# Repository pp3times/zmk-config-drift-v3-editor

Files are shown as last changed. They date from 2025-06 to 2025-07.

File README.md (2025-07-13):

## Drift Keyboard V3 by Timception - Dual Roller Encoder Firmware   

- This is the wireless [ZMK](https://zmk.dev/) version of the [Original Drift Keyboard](https://github.com/Timception/Drift)  

  - [Default Keymap](#default-keymap) to see where all your keys are, or go straight to the:  
  
    - [Keymap Editor by Nick Coutsos](https://nickcoutsos.github.io/keymap-editor/)  

- The PCB is not open source, but you could [contact me](https://www.instagram.com/majin.keyboards) if you would like a pair
  <br/>  

## Quickstart Guide   
  - [1.	How to change your keys](/docs/change-keys/) - Detailed guide on how to change your keys  

  - [2.	How to install batteries](/docs/batteries/) - Along with other supported batteries  

  - [3.	Connecting through Bluetooth](/docs/bluetooth/) - Bluetooth connections and troubleshooting  

  - [4.	Charging](/docs/charging/) - How to charge the keyboard and use with USB-C  

  - [5.	Switching to low profile](/docs/low-profile/) - Remove some parts to use low profile switches  

  - [6.	3D Printables](https://github.com/Timception/3d-printables) - This will take you to the 3D printable part repository  
<br/><br/>  

# Default Keymap

  - This keyboard is powered by [ZMK](https://zmk.dev/), an open‑source firmware. ZMK lets you place several “layers” of key functions on the same physical keys. When you press a designated layer key—much like holding "Fn" on a laptop—the keyboard shifts to a different layer, giving you extra controls (for example, volume, brightness, or any custom shortcuts) without adding more keys.  

  - Split keyboards come with their own set of terms, and one important one to know is the “thumb cluster.” This refers to the group of keys at the bottom in the form of an arc where a traditional keyboard would have the spacebar.  
    
  - Unlike standard keyboards, split keyboards make better use of this space by letting you place and customize useful keys there. This reduces the need to reach for commonly used keys.  

  - For example, on this keyboard, I’ve placed Shift on the left-most thumb cluster key and Backspace on the right-most. The spacebar is in the center of each thumb cluster—so whether you hit the spacebar with your left or right thumb, it’s easy to reach.  

  - You can [change the keys on your keymap](/docs/change-keys/) if you prefer different placing of any key.  

> [!Note]  
> The "&trans" keys seen on the thumb clusters on layers 1 and above act as transparent keys, copying the key set on the layer beneath it.  
> If you are confused about what some of these keys represent, you may find [more information here](https://zmk.dev/docs/keymaps/list-of-keycodes)  
> Information on layers can also [be found here](https://zmk.dev/docs/keymaps/behaviors/layers)  

## Base/Default Layer (layer 0)  
- This is the default layer or layer 0 on this keyboard and the keys are as follows:  
  
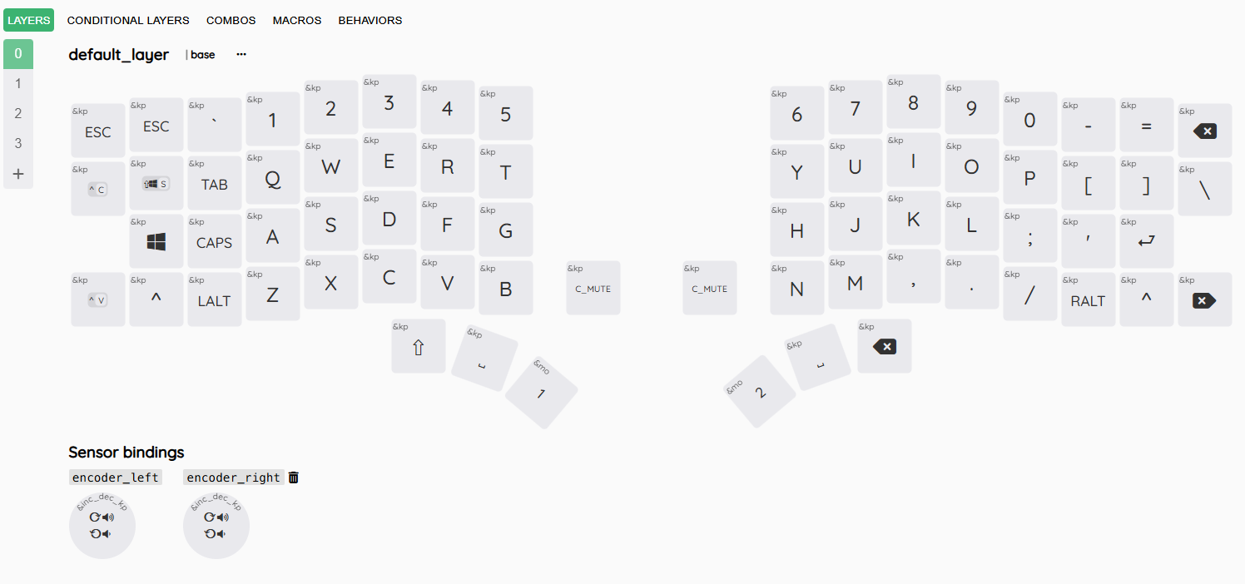
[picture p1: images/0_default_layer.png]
  <br/><br/>  

## Lower Layer (layer 1)  
- This is the lower layer or layer 1. This is where the F-Keys and Arrow-Keys are:  
  
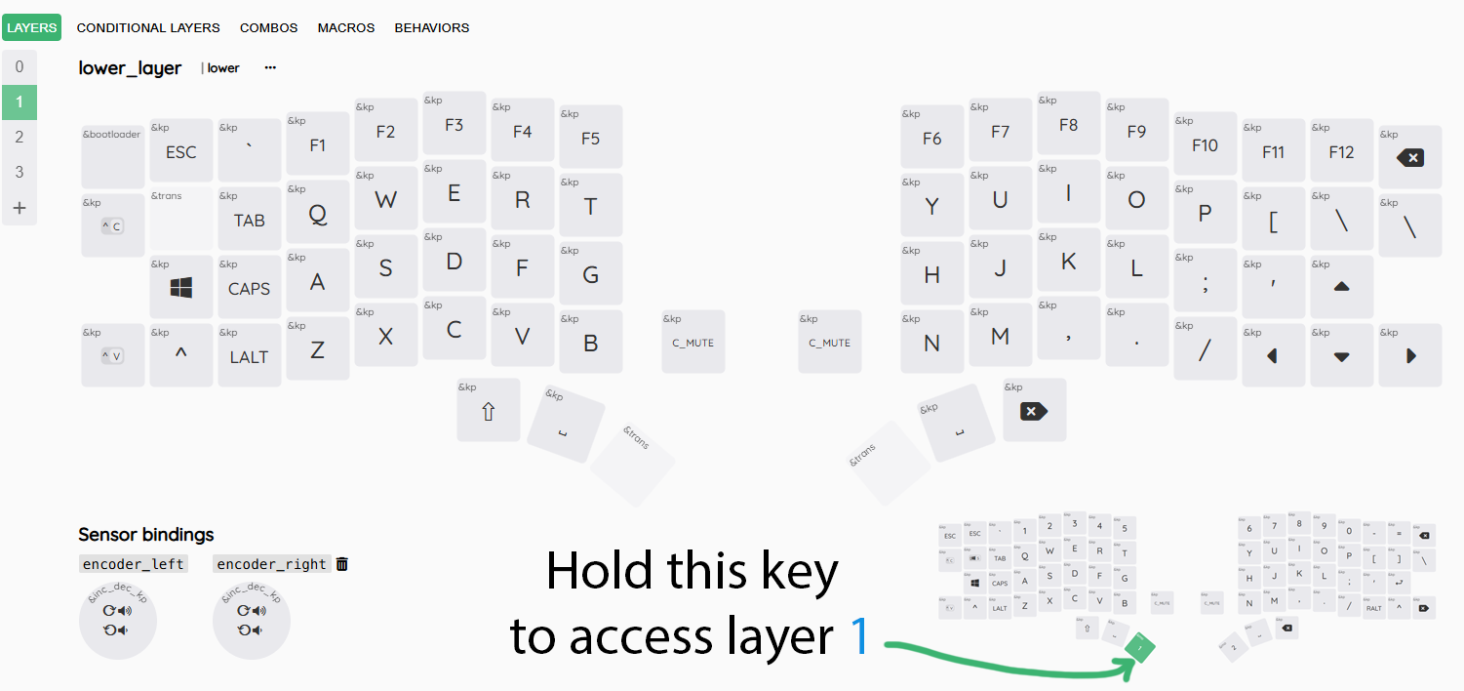
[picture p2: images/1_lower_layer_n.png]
    
  The "&mo 1" key is held to access this layer as seen in the bottom right of this image.  <br/><br/>  

## Raise Layer (layer 2)  
- This is the lower layer or layer 2. This is where the Bluetooth Functions and Mouse Keys are:  
  
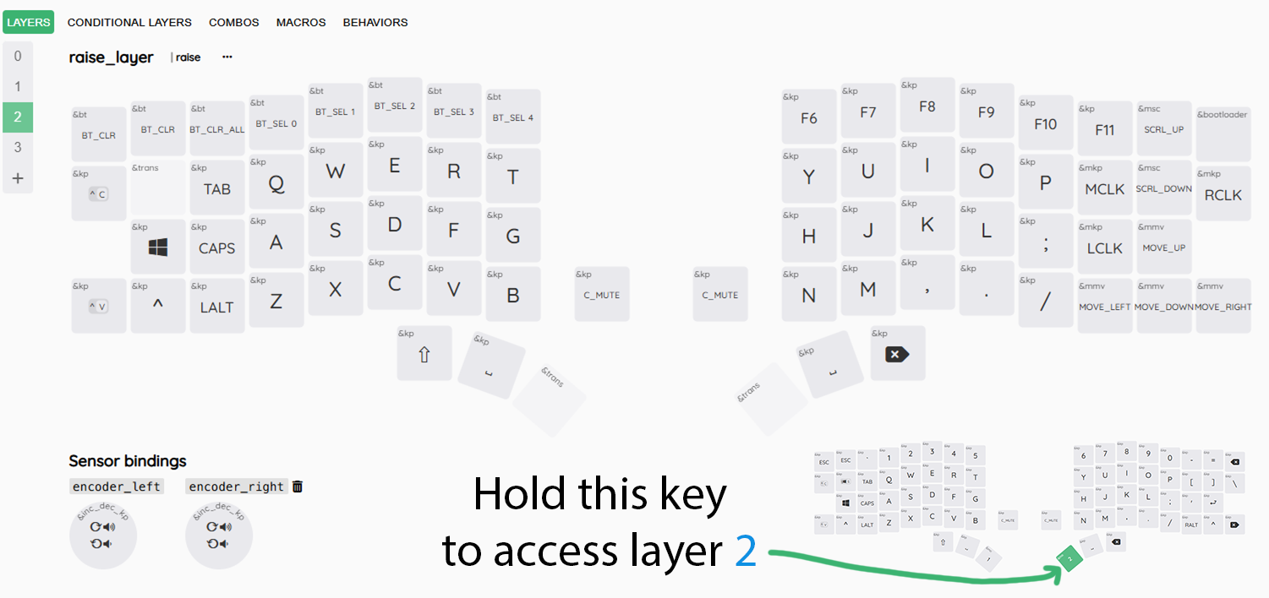
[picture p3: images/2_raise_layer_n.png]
    
  The "&mo 2" key is held to access this layer as seen in the bottom right of this image.  <br/><br/>  

## Adjust Layer (layer 3)  
- This is the adjust layer or layer 3. This is pretty much a clone of Layer 2 as my usage doesn't go beyond 3 layers:  
  
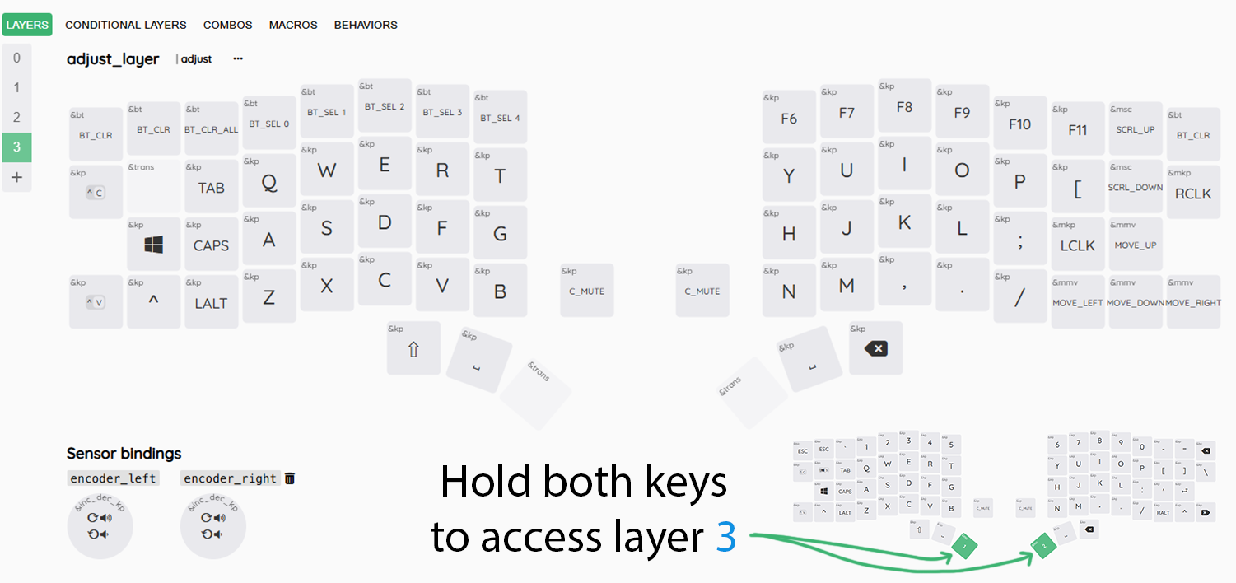
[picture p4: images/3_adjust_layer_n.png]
    
   Both "&mo 1" and "&mo 2" keys are held to work together to activate the conditional layer function, taking us to layer 3.  <br/><br/>  

This version of the Drift Keyboard supports:  

 - 5-Pin MX switches (3-Pin switches will also work)  
 - Kailh Choc V1 switches  
 - Kailh Choc V2 switches  
<br/>  

How to [change your build](/docs/low-profile/) to use choc switches.  
<br/>  

  
<br/>  

>[!Warning]
>Important Note on LiPo Batteries  
>  
>LiPo (Lithium Polymer) batteries are considered a fire hazard due to their sensitivity
>to overcharging, punctures, or improper handling, which can lead to overheating or combustion.
>Because of strict shipping regulations, LiPo batteries cannot be included with this keyboard
>and must be purchased separately by the builder.  
>  
>Disclaimer: I am not responsible for any damage, injury, or loss resulting from the use,
>charging, or installation of LiPo batteries. Use at your own risk and follow all safety guidelines
>provided by the battery manufacturer.  
>  
>More on how to install batteries [here](/docs/batteries/)  
<br/><br/>  

You can see more actual builds [HERE](https://www.instagram.com/majin.keyboards)  

This project was made possible thanks to the incredible support of [Friction](https://github.com/friction07)  
Your generosity truly made all the difference—thank you!

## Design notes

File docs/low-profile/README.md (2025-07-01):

## Drift Keyboard Choc Conversion
This is how to convert to a low-profile choc version:  

### Basically you only have to remove one layer of the outer acrylic frame  
<br/>

 - Disassemble your drift keyboard then remove all the brass standoffs  
 
 - Replace all the brass standoffs with 4mm brass standoffs  
 
 - The top screws under the keys should be changed to 4mm M2 screws if they are not already that length.  
 
 - You will need to use the [Choc Plate](https://github.com/Timception/3d-printables/tree/main/v3/plates/low-profile) which is slightly different from the MX switch plate.  
 <br/><br/>  
 
### This is what your Drift Keyboard should look like after the conversion:  
<br/><br/>  

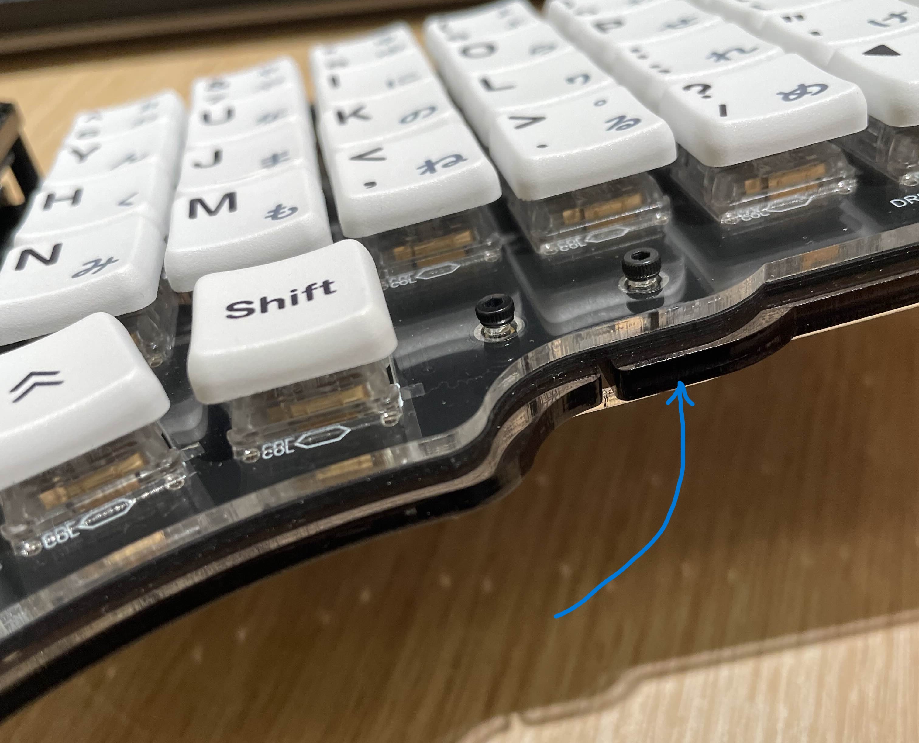
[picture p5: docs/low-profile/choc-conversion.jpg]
  

Only one layer of outer acrylic beneath the pcb, and the plate is now sandwiched flush with the pcb.

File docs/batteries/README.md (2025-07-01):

# Battery Installation  

## Contents:  

 - [3D Printables for PS3 Controller Battery Pack](https://github.com/Timception/3d-printables/tree/main/v3/battery-pack) - Takes you to the 3D printables page for these parts
 
 - [Batteries](#batteries-tested-to-work-with-the-keyboard) - Some batteries you can use for this keyboard  
   
 - [Screwing on the PS3 controller battery pack](#screwing-on-the-ps3-controller-battery-pack) - Start of the assembly guide  
 
 - [Plugging in the Battery Connector](#plugging-in-the-battery-connector) - Hooking up the battery  
 
 - [Plugging in the 4-Pin OLED](#plugging-in-the-4-pin-oled) - Standard (power hungry) OLED  

## Alternate Battery:  
 
 - [Using the 110mAh LiPo Battery](#using-the-110mAh-lipo-battery-instead) - the smaller battery option (removing the OLED dramatically improves battery life)  

## Alternate Display:  
 
 - [Replacing the 4-Pin OLED with a NiceView](#replacing-the-4-pin-oled-with-a-niceview) - Best screen to use if you install the 110mAh battery  
<br/><br/>

>[!Warning]
>Important Note on LiPo Batteries  
>  
>LiPo (Lithium Polymer) batteries are considered a fire hazard due to their sensitivity
>to overcharging, punctures, or improper handling, which can lead to overheating or combustion.
>Because of strict shipping regulations, LiPo batteries cannot be included with this keyboard
>and must be purchased separately by the builder.  
>  
>Disclaimer: I am not responsible for any damage, injury, or loss resulting from the use,
>charging, or installation of LiPo batteries. Use at your own risk and follow all safety guidelines
>provided by the battery manufacturer.  
<br/><br/>  

## Batteries tested to work with the keyboard

- 1800mAh PS3 Controller Battery (LIP1359)
   
  - [Amazon Item Link](https://a.co/d/4CgXvFp)  
  - [Aliexpress Item Link](https://www.aliexpress.com/item/1005005213892382.html)  
  <br/>  

- 120mAh LiPo Battery (401230) + JST PH2.0mm - This battery is small enough to fit under the MCU
  
  - [Aliexpress Item Link](https://www.aliexpress.com/item/1005003383250806.html)  
  <br/>  
  
- 110mAh LiPo Battery (401030) + JST PH2.0mm - This battery is small enough to fit under the MCU
  
  - [Ebay Item Link](https://www.ebay.com/itm/124961007813)  
  - [Aliexpress Item Link](https://www.aliexpress.com/item/1005006161362814.html)  
  <br/>  

## Screwing on the PS3 controller battery pack  

1. Make sure this screw is already screwed into the nylon standoff on the other side.  

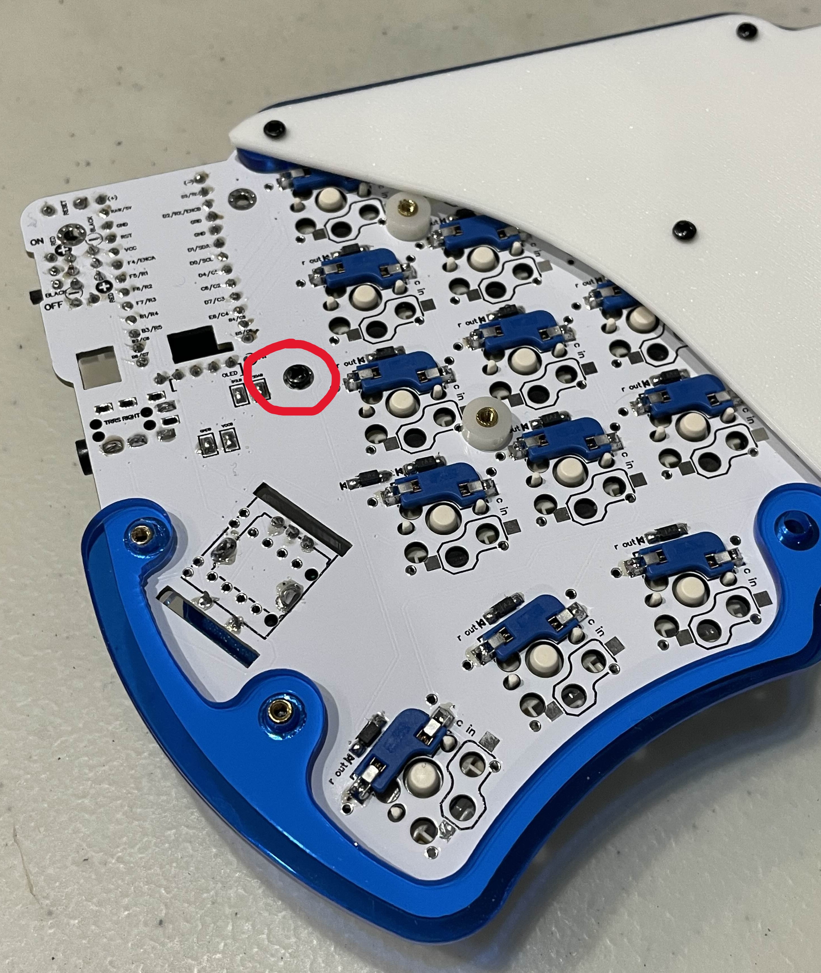
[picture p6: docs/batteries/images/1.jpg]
<br/><br/>

2. Place Bottom Plate Section and Screw in this 12mm screw first.  

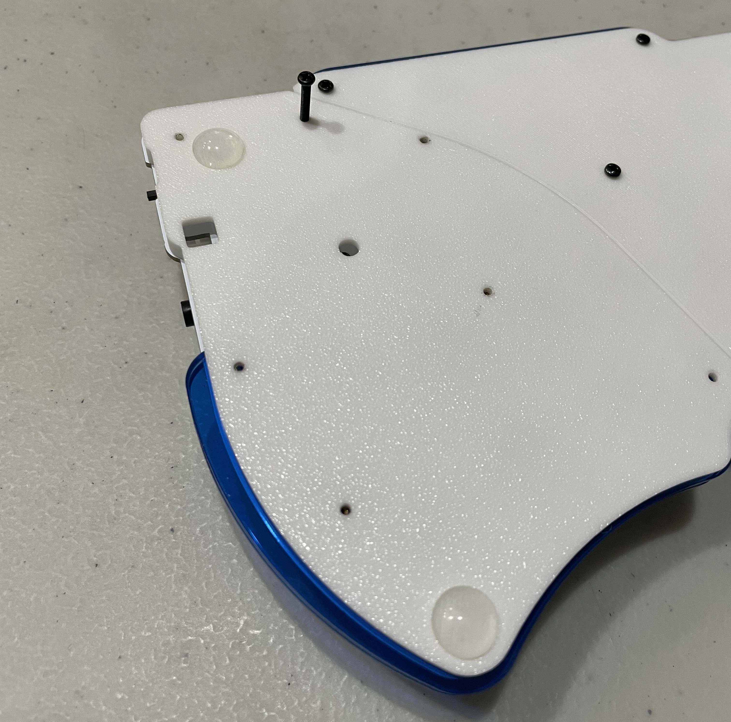
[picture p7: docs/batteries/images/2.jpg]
<br/><br/>

3. Screw in the nylon standoff as shown below.  

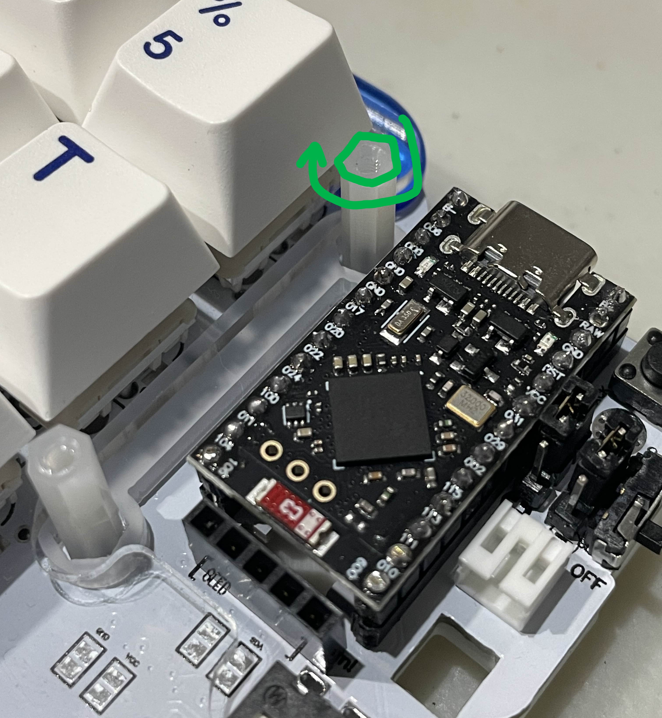
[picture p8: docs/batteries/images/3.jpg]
<br/><br/>

4. Here is how the battery will fit in the 3D-Printed battery pack.  

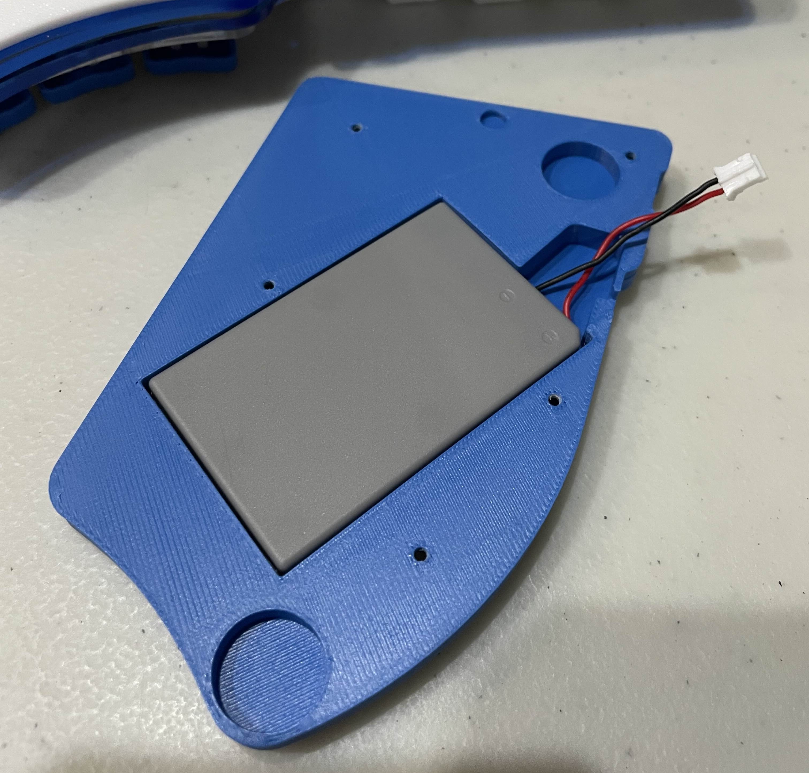
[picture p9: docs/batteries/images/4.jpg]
<br/><br/>

5. First, put the JST PH2.0 battery connector through to the other side as shown below.  

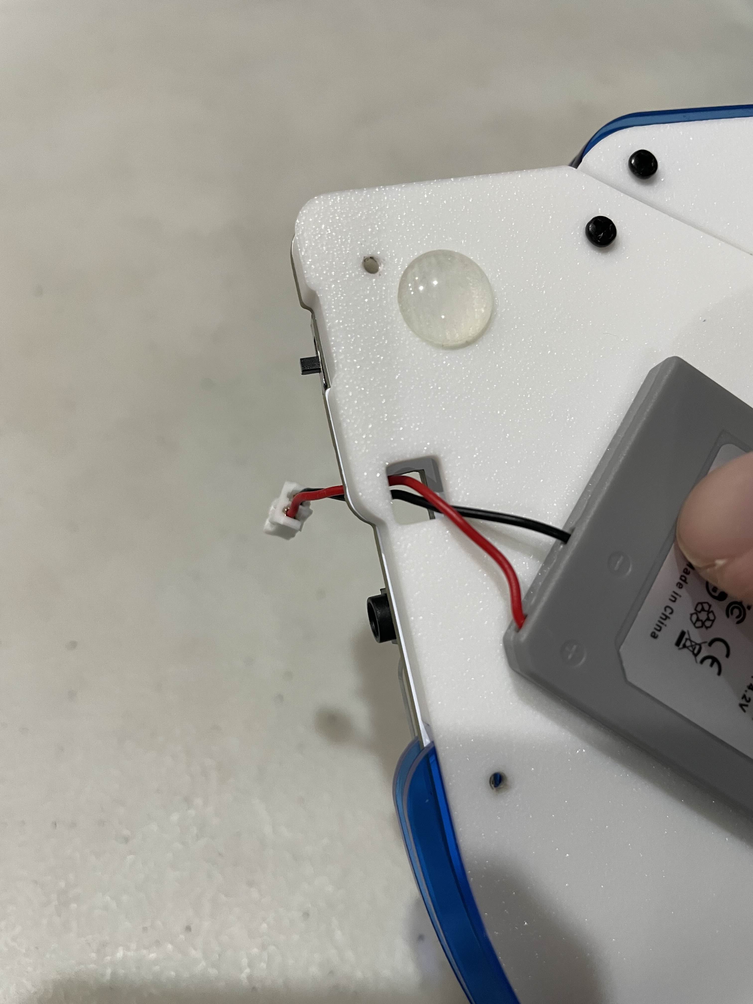
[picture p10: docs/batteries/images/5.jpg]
<br/><br/>

6. Next, carefully place the battery cover over the battery.  

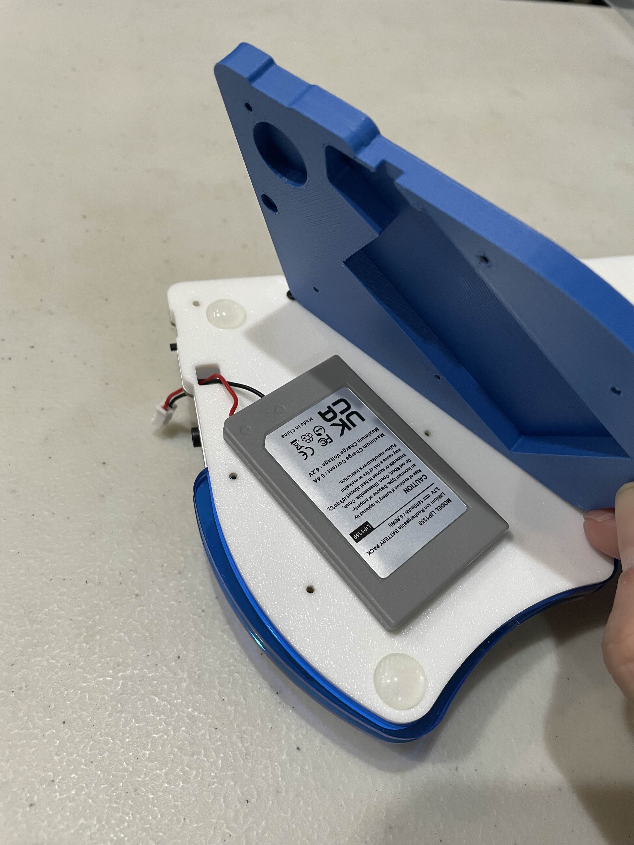
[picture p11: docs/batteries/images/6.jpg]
<br/><br/>

7. Align/Adjust the cover so the screw holes match the plate underneath.  

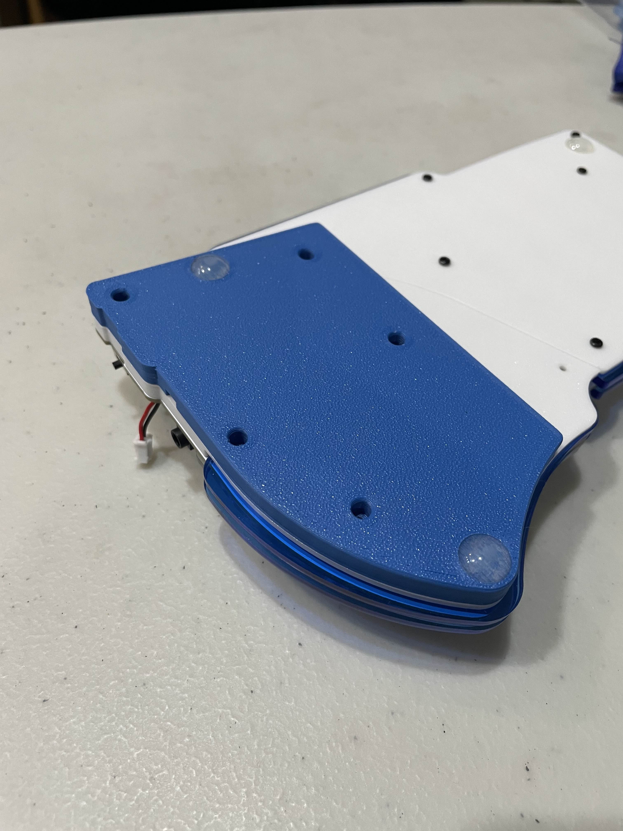
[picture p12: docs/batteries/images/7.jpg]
<br/><br/>

8. Now screw in this 5mm M2 screw as shown in the image.  

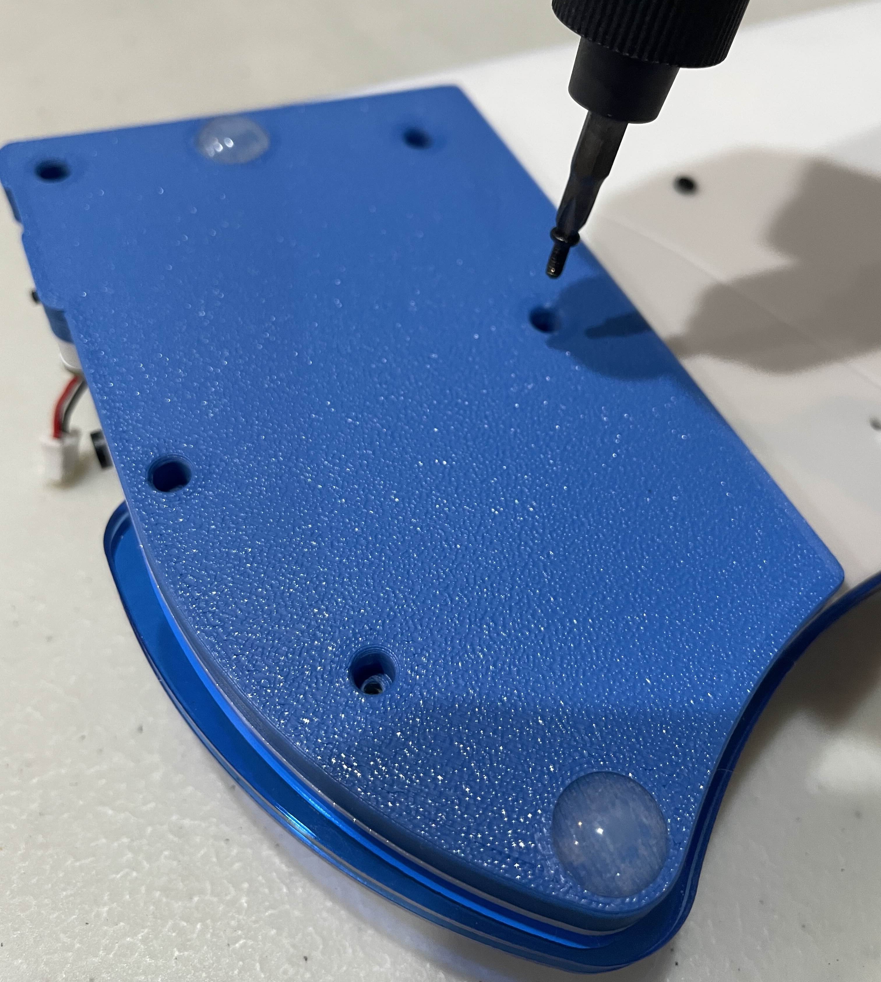
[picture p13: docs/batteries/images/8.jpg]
<br/><br/>

9. Next, screw in this screw.  

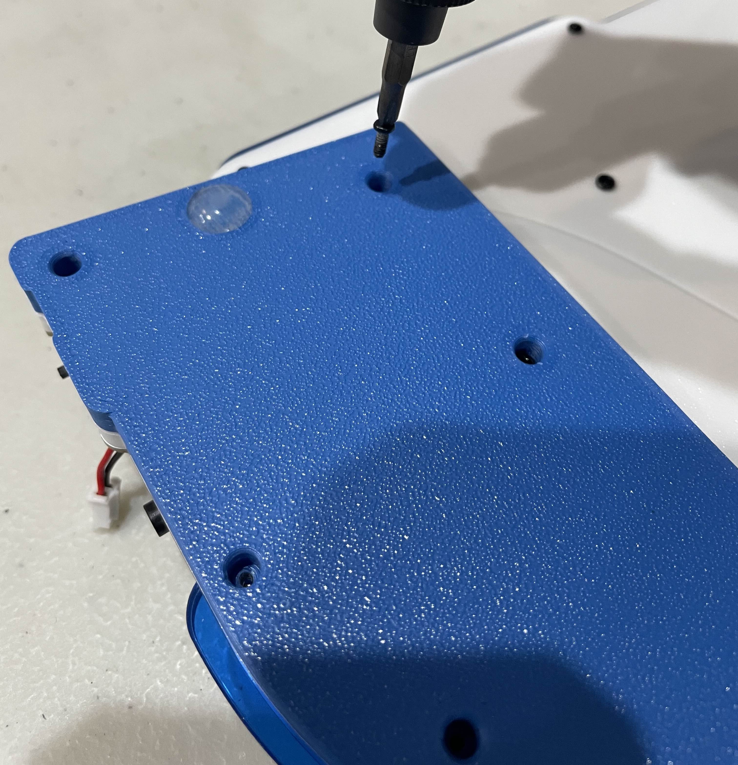
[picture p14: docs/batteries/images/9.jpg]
<br/><br/>

10. Then this 12mm screw as shown.  

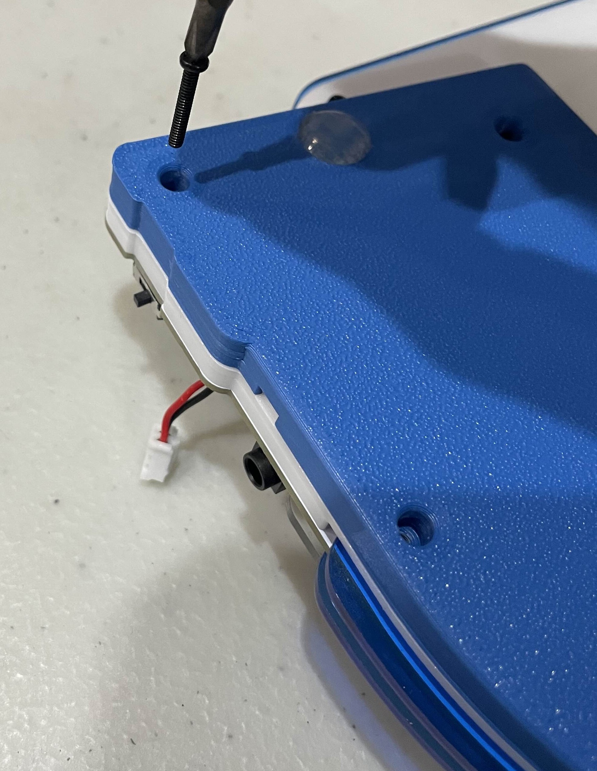
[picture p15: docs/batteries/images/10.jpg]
<br/><br/>

11. Screw in the nylon standoff seen just under the RESET switch.  

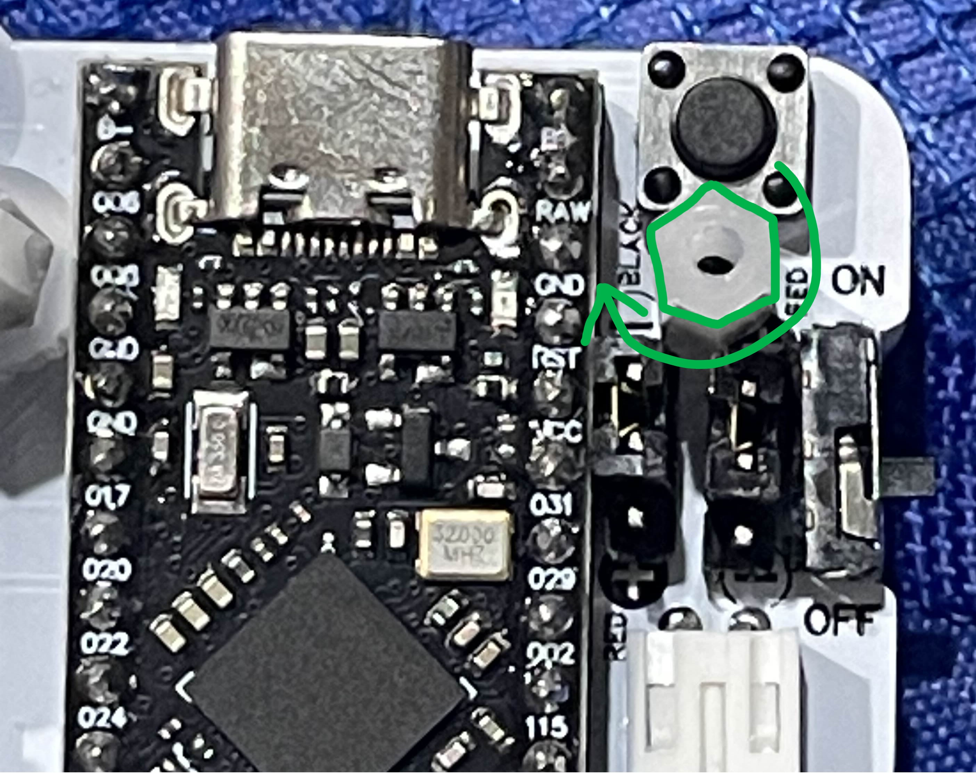
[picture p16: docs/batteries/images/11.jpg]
<br/><br/>

12. Next screw back in the hex nut with the brass standoff and leave the allen key wrench in.  

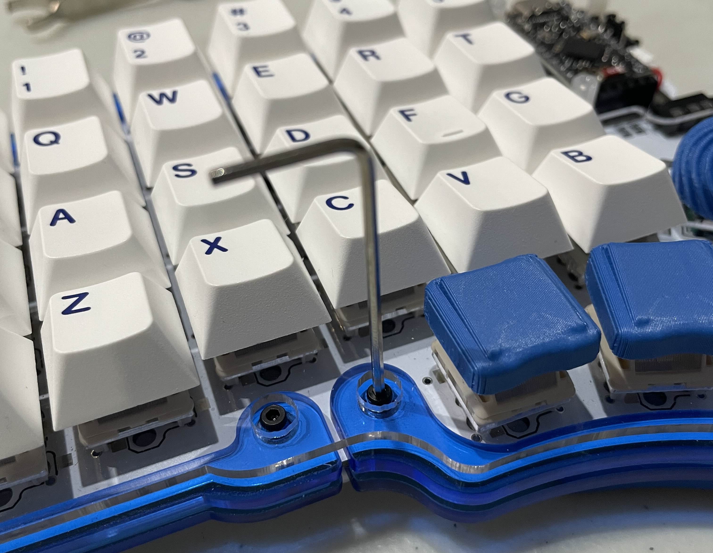
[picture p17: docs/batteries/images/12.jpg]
<br/><br/>

13. Hold the allen key wrench in position to prevent it from spinning as you screw in from the other side as shown below.  

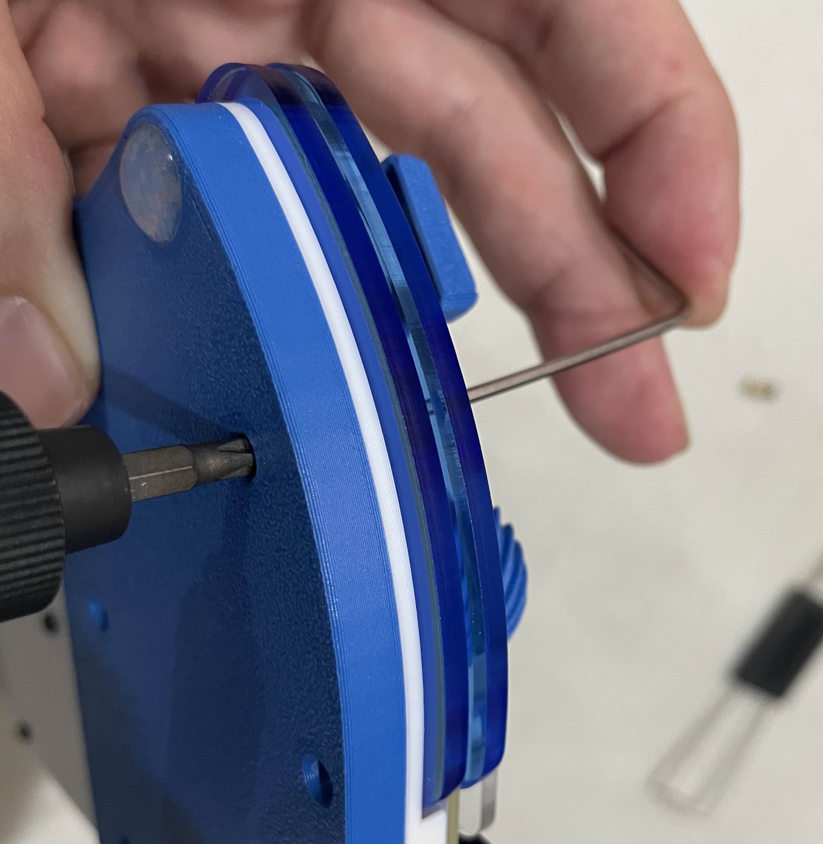
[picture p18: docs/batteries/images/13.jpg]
<br/><br/>

## Plugging in the Battery Connector  

14. Now insert the battery connector by hand, with the help of tweezers or the switch puller as shown.  

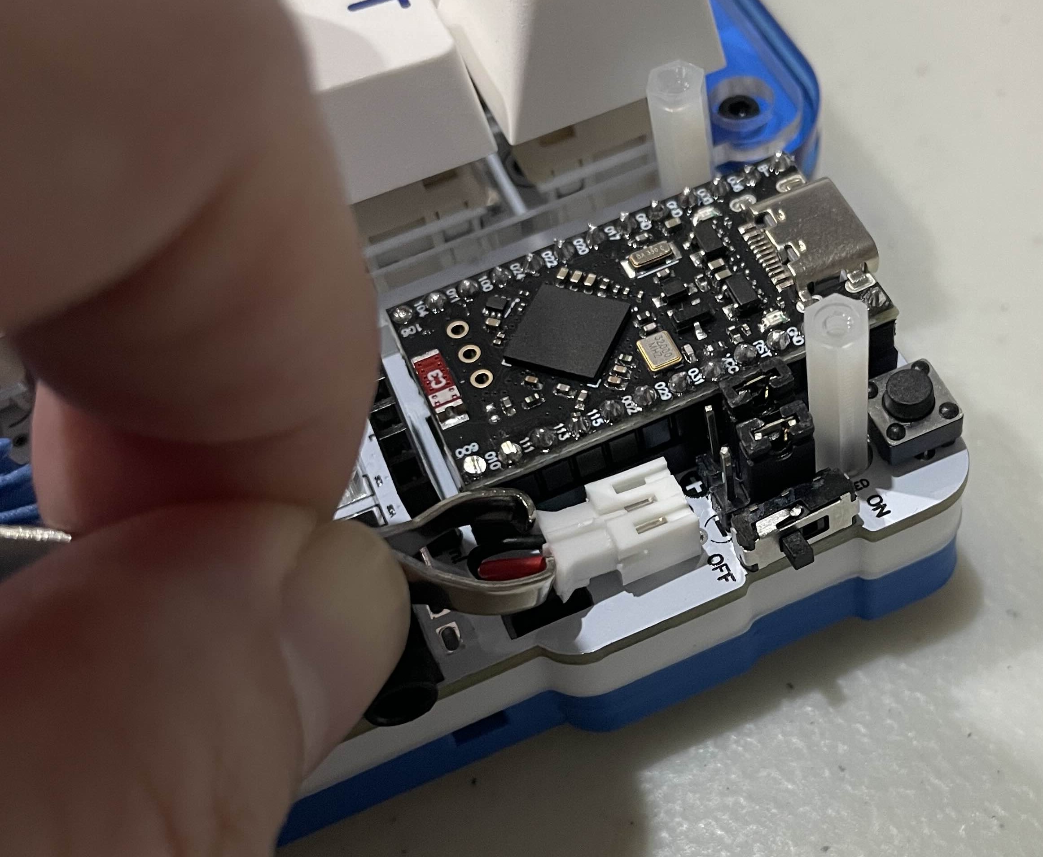
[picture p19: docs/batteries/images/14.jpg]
<br/><br/>

15. Make sure the jumpers are over the correct pins as shown in the image (they should be correct straight out of the box).  

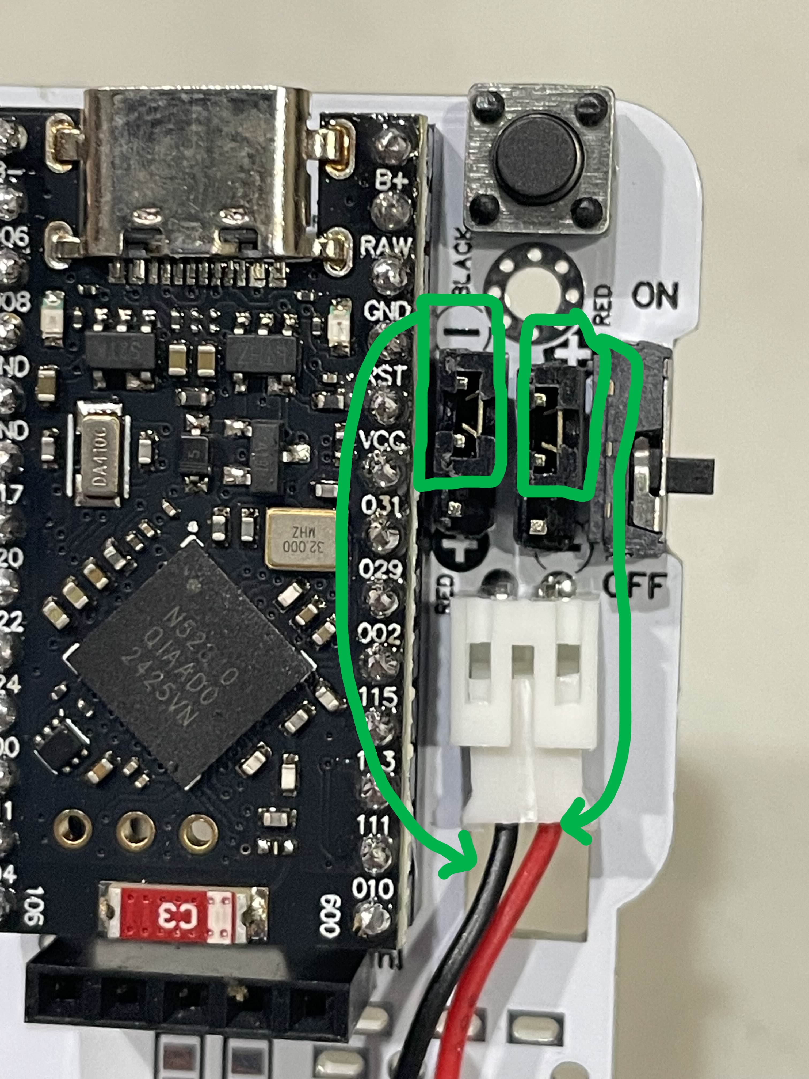
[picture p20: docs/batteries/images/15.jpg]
<br/><br/>

16. Do the same for the right half and see if the cable colors and jumpers are the same as in the image below.  

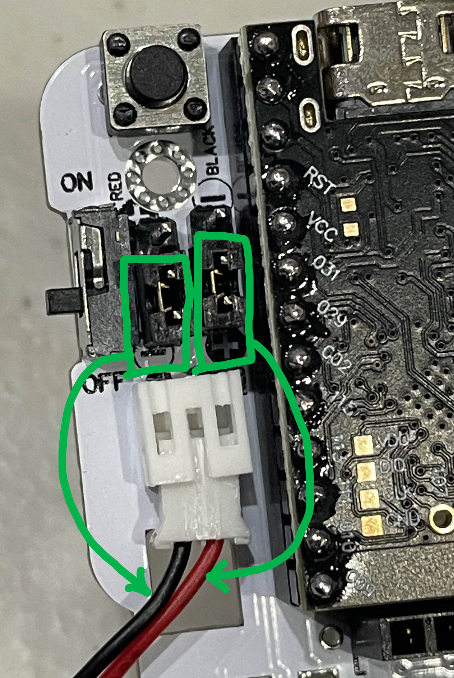
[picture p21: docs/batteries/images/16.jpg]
<br/><br/>

17. Place the 3D-Printed cover over the MCU so that it is flush with the PCB.  

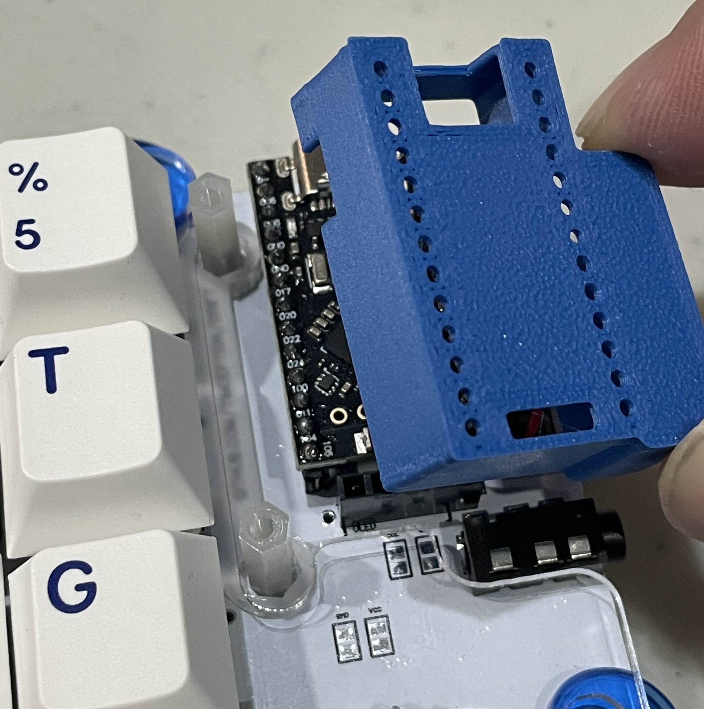
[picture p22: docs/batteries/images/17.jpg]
<br/><br/>

## Plugging in the 4-Pin OLED  

18. Insert the 4-Pin OLED into the left female pin headers as shown in the image for both sides.  

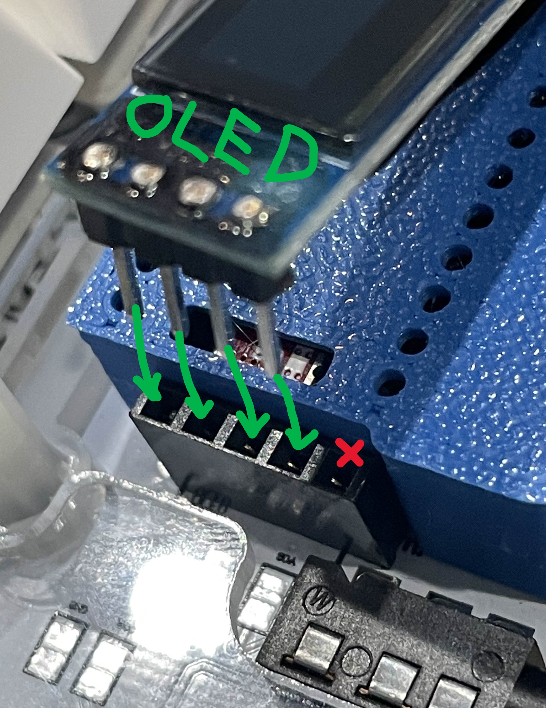
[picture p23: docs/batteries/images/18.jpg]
<br/><br/>

# Using the 110mAh LiPo Battery instead  

19. Remove the MCU carefully with a switch puller.  

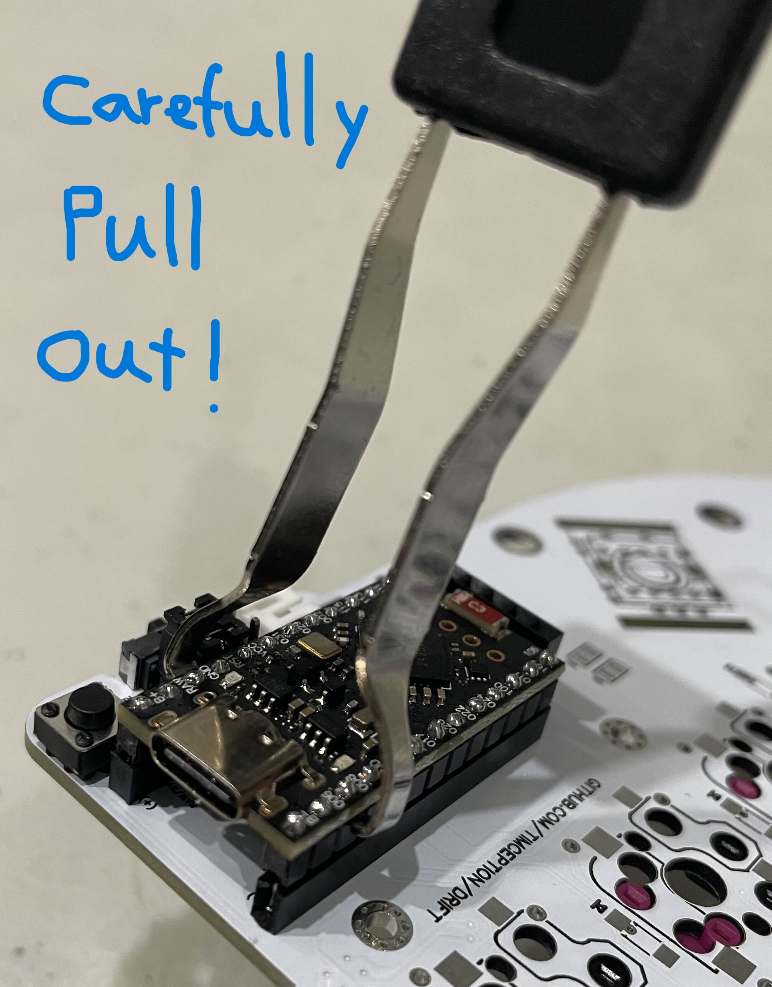
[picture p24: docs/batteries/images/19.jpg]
<br/><br/>

20. Insert the connector through the hole as shown.  

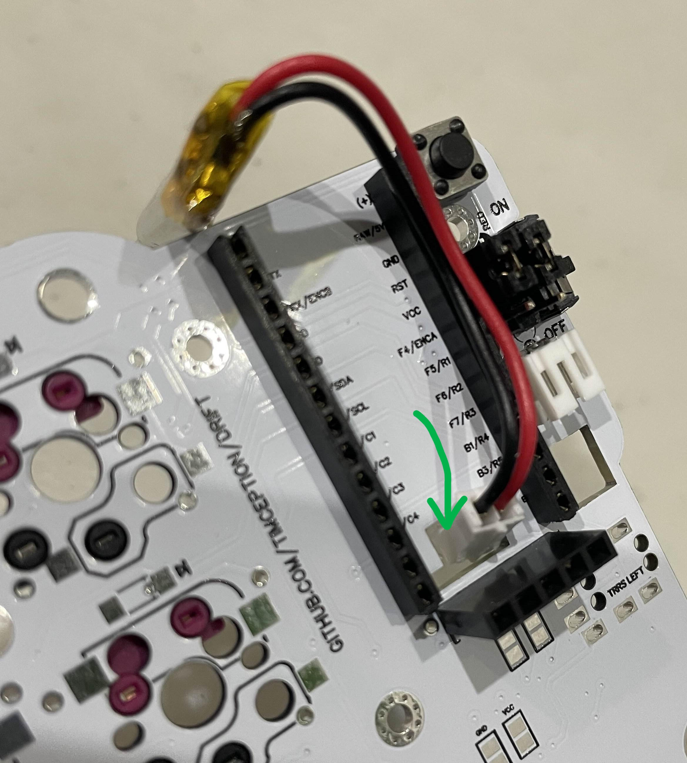
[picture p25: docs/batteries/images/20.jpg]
<br/><br/>

21. Push the connector back out the other hole as shown.  

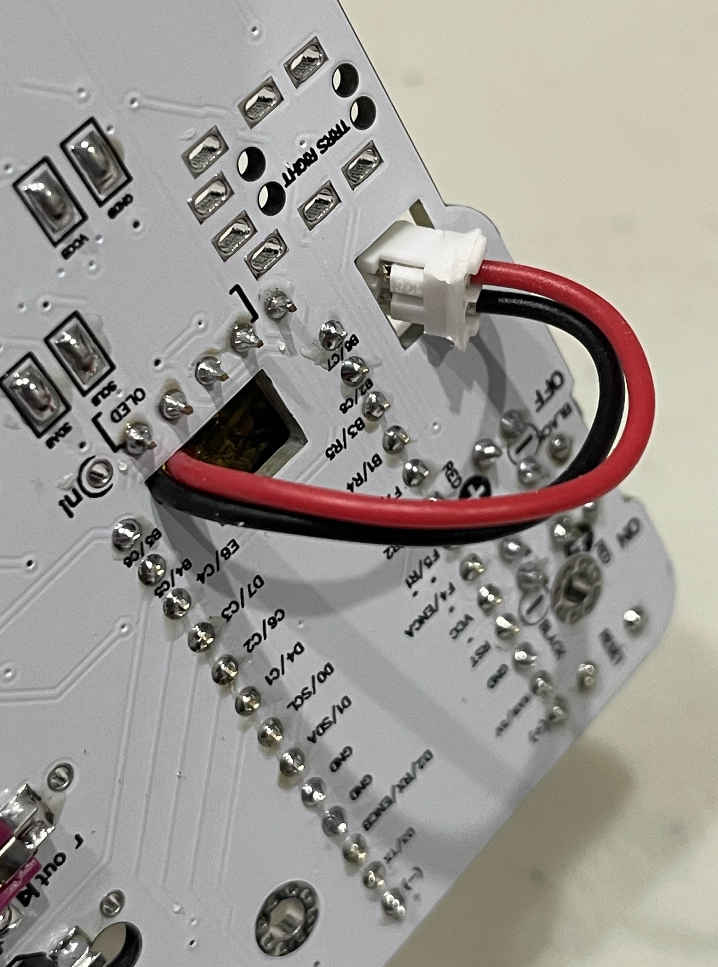
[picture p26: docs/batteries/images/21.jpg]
<br/><br/>

22. Try to avoid the pins puncturing into the wire to prevent unwanted short circuits (electrical tape can be used to cover the pins).  

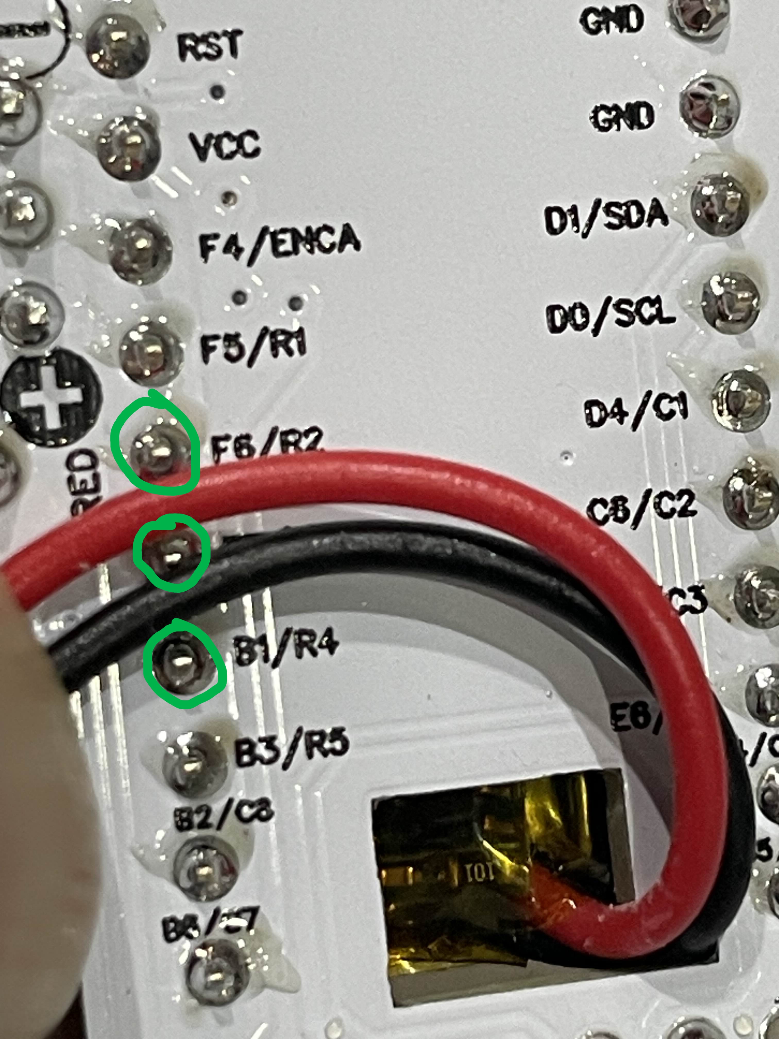
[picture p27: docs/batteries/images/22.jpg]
<br/><br/>

23. Check that you have moved the pins to the correct positions as shown before plugging in the battery connector.  

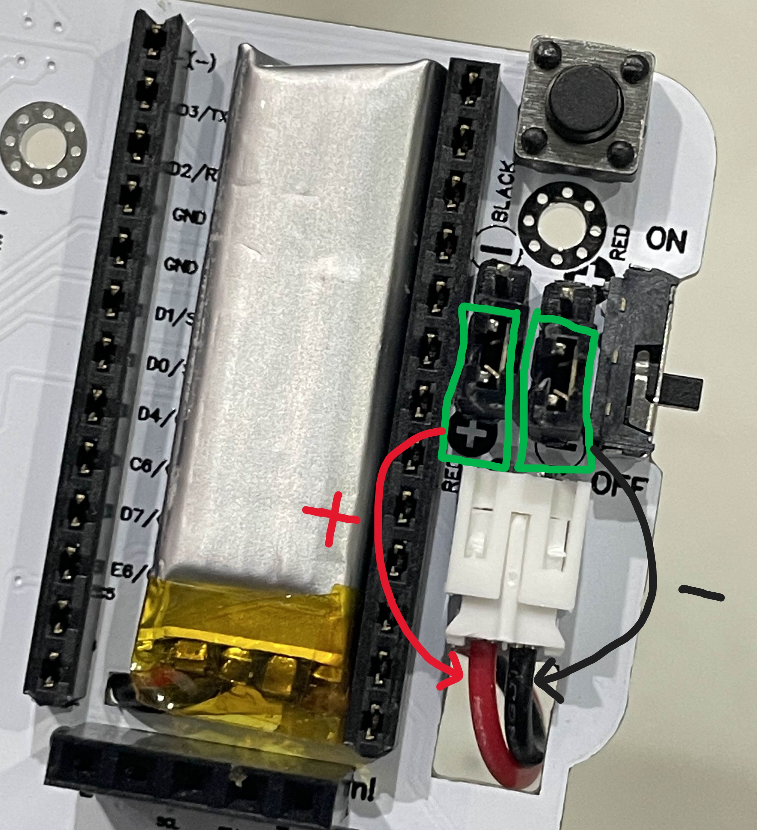
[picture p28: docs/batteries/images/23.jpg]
<br/><br/>

24. Carefully push the MCU back into its place with the pins aligned correctly.  

<br/><br/>

25. Repeat the process for the right half with the jumpers placed as shown.  

<br/><br/>

# Replacing the 4-Pin OLED with a NiceView

26. You can replace the normal OLED with a super efficient screen famously known as the [Nice!View](https://nicekeyboards.com/nice-view/)

> [!Warning]  
> You will need to flash a [special version of firmware](https://github.com/Timception/zmk-config-drift-v3-nv-editor) on to both sides before inserting the Nice!View
> 
<br/><br/>

> [!Note]
> If you forgot how to fork and compile your own firmware, [please refer to this guide](https://github.com/Timception/zmk-config-drift-v3-editor/tree/main/docs/change-keys)
<br/><br/>

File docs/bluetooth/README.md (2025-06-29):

# Testing or Fixing your Bluetooth Connection

- ## Connect to Mutliple Devices  

  - Once you turn on your split keyboard you can clear the current bluetooth profile just to make sure it is available by pressing the BT_CLR or BT_CLR_ALL key on layer 2.  
  
  - You can enable/refresh bluetooth on your host device to search for this keyboard and connect to it. If it says unable to connect - you can try clicking on the device in the list repeatedly (I spam click in Windows until it connects).  
  
  - This keyboard has the ability to connect to 5 devices across 5 Profiles (BT_SEL 0 to BT_SEL 4).  
  
  - By holding down mo2 as shown below, you have access to the bluetooth functions on the top left half:
  - <br/>  
    
    - BT_CLR: Clear the connection between the keyboard and host for the selected profile.  
	
    - BT_CLR_ALL: Clear the connection between the keyboard and host for all profiles.  
	
    - BT_SEL 0 to BT_SEL 4: Pressing BT_SEL 0 will activate the first bluetooth profile, BT_SEL 1 will activate the second, and so on..  
	
    - If thirsty for more information [CLICK HERE](https://zmk.dev/docs/keymaps/behaviors/bluetooth)  

- ## Clearing a Bluetooth Profile (also removing keyboard from host device)  

  - After pressing BT_CLR or BT_CLR_ALL, you will also have to remove the device from your host. Usually this consists of going into the host device's bluetooth settings with bluetooth turned on and manually removing the drift keyboard from the list of devices (if any).  

<br/><br/>

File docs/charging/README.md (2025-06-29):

# Charging and Wired Connection

- The keyboard halves must be charged individually through their USB-C port, with the power switches turned on.

- Standard USB-C phone chargers (5V, 1A–2.4A) will also work.

- A blue light will appear near the USB-C port while charging. The light turns off when charging is complete.
<br/><br/>

> [!Note]  
> You can usually see the battery percentage of connected Bluetooth devices on your computer or phone.  
> Because of this, an OLED screen is not really needed, unless you use [these](https://typeractive.xyz/products/nice-view). Removing the OLED can greatly improve battery life.  
> If you want to use this keyboard through a USB-C wired connection without charging, both sides must be connected to your computer individually.  

> [!Warning]  
> Connecting only the right half will not work. However, connecting only the left half will work.  
> This is because the right half must first communicate with the left half before sending signals to the computer.  
> As a result, the battery on the left half drains faster than the right.  
<br/>

- [ZMK Power Profiler](https://zmk.dev/power-profiler) - Please check this out to estimate your keyboard's power usage and battery life with different components.  
<br/>


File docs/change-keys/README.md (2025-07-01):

# How to Change your Keymap on GitHub (step by step)  

## Summary of tasks:  

  - Login to GitHub, [fork keyboard repository](#1-fork-this-repository)  
  - [Enable workflows/actions](#4-enable-workflows) (to pump out your own firmware)  
  - [Enable keymap editor](#12-click-the-keymap-editor-link) (to edit your keymap)  
  - [Save keymap changes](#24-click-save-at-the-top-to-save-your-new-keymap), download new firmware  
  - [Flash keyboard firmware](#28-plug-left-half-of-the-drift-keyboard-into-your-computer-then-double-click-the-reset-button) one side at a time, enjoy  
<br/><br/>  

## Follow the illustrated guide below if this is your first time  

### 1. Fork [This Repository](https://github.com/Timception/zmk-config-drift-v3-editor)  

<br/><br/><br/>  

### 2. Set Repository Name and Create Fork  

<br/><br/><br/>  

### 3. Go to the Actions Tab  

<br/><br/><br/>  

### 4. Enable Workflows  

<br/><br/><br/>  

### 5. Click Build your ZMK Firmware  

<br/><br/><br/>  

### 6. Run Workflow  

<br/><br/><br/>  

### 7. Wait for GitHub to Compile Firmware Files  

<br/><br/><br/>  

### 8. Click the Firmware Link after Build Complete  

<br/><br/><br/>  

### 9. Download Firmware  

<br/><br/><br/>  

### 10. Unzip to Find 3 Files: Firmware Files for the Left and Right Keyboard Halves and a Reset File  
This confirms that you can now make your own firmware. Next, let's try and change some keys.  

<br/><br/><br/>  

### 11. Go Back to the Repository Page  

<br/><br/><br/>  

### 12. Click the [Keymap Editor Link](https://nickcoutsos.github.io/keymap-editor/)  

<br/><br/><br/>  

### 13. Authenticate with GitHub  

<br/><br/><br/>  

### 14. Authorize Keymap Editor  

<br/><br/><br/>  

### 15. Add Repository  

<br/><br/><br/>  

### 16. Add Select Repository - Drift V3  

<br/><br/><br/>  

### 17. After Installation - Keymap will Appear  

<br/><br/><br/>  

### 18. Click the Layer Numbers to View the Keys on Each of those layers  

<br/><br/><br/>  

### 19. You can Access the Bluetooth Functions by Pressing and Holding "mo2"  

<br/><br/><br/>  

### 20. Bluetooth Functions [(more on this here)](https://github.com/Timception/zmk-config-drift-v3-editor/tree/main/docs/bluetooth)  

<br/><br/><br/>  

### 21. Click the "Alt" Key to bring up the Behaviour Settings for that Key  

<br/><br/><br/>  

### 22. Click the Current Key in the Key Code Field  

<br/><br/><br/>  

### 23. Find the Shift Keycode by using the Search Bar then Click "Okay"  

<br/><br/><br/>  

### 24. Click "Save" at the top to Save your New Keymap  

<br/><br/><br/>  

### 25. Note the Changes you Made (optional) and Click "Commit"  

<br/><br/><br/>  

### 26. Click Firmware File Link to go to the Firmware Building Page  

<br/><br/><br/>  

### 27. Download New Firmware after Everything is Green and Complete  

<br/><br/><br/>  

### 28. Plug Left Half of the Drift Keyboard into your Computer then Double-Click the RESET Button  

<br/><br/><br/>  

### 29. A New Drive Should Appear (for you to upload your firmware file)  

<br/><br/><br/>  

### 30. Drop the Firmware for the Left Side into that Drive and Wait for Transfer to Complete  

<br/><br/><br/>  

### 31. Repeat Steps for the Right Half and Drop the Appropriate Firmware File into its Drive  

<br/><br/>

### 32. Test Keys Using This [Online Key Tester](https://www.keyboardtester.com/tester.html) or Download [Switch Hitter](https://www.majorgeeks.com/files/details/switch_hitter.html)  

<br/><br/>

For more information on Behaviours and Key Codes please visit: [ZMK Behaviours](https://zmk.dev/docs/keymaps/behaviors)  

You can see more actual builds [-=HERE=-](https://www.instagram.com/majin.keyboards)

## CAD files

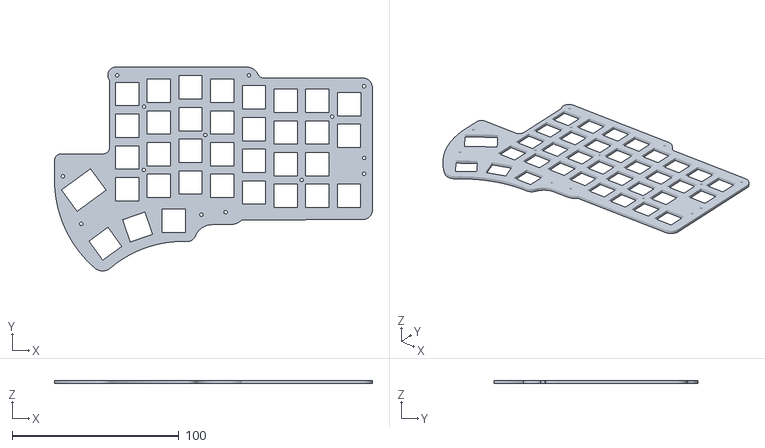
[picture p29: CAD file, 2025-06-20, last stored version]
Drift-V2-and-V3-Choc-Plates/Drift-V2-and-V3-Full-Size-Choc-Plate-right.stl
190.6 x 122.2 x 2.00

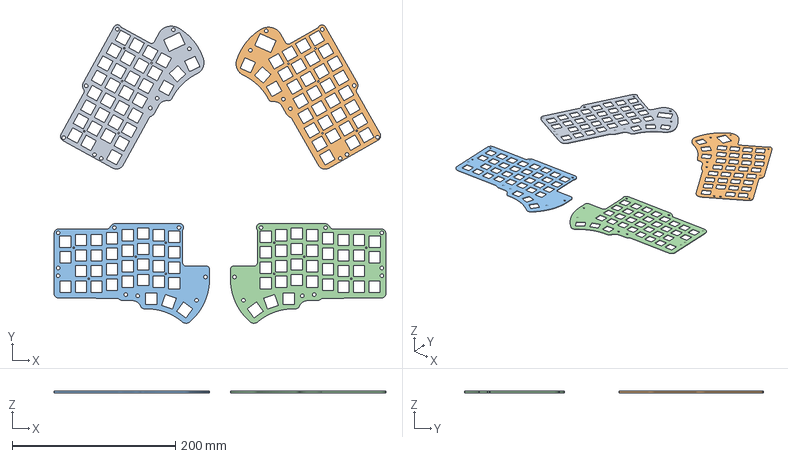
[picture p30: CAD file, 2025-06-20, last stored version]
Drift-V2-and-V3-Cherry-Plates/Drift-V2-and-V3-Cherry-Plates.3mf
406.6 x 365.7 x 2.00 mm
Drift V2 Cherry Plate A1 Mini.stl x 2
Drift-V2-and-V3-Full-Size-Cherry-MX-Plate-left.stl
Drift-V2-and-V3-Full-Size-Cherry-MX-Plate-right.stl

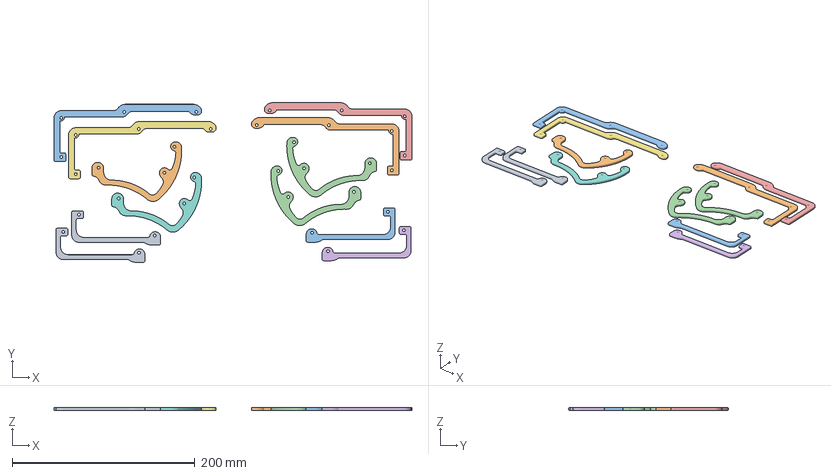
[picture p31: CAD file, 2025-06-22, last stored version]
Outer-Acrylic/Outer-Acrylic-Fillet.3mf
392.3 x 175.1 x 3.00 mm
Bottom Left Acrylic (1) x 4
Bottom Right Acrylic (1) x 4
Top Acrylic (1) x 4

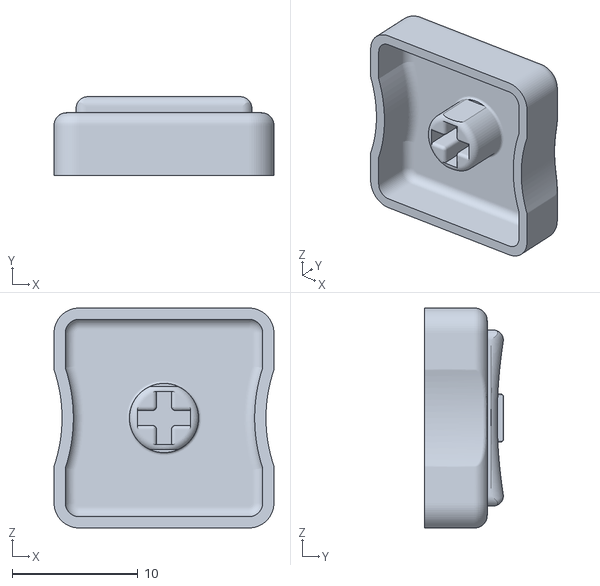
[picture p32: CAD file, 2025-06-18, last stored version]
printables/Cherry-MX/Otaru-Keycaps-by-Timception-Ribbed-Key.stl
17.5 x 6.30 x 17.5

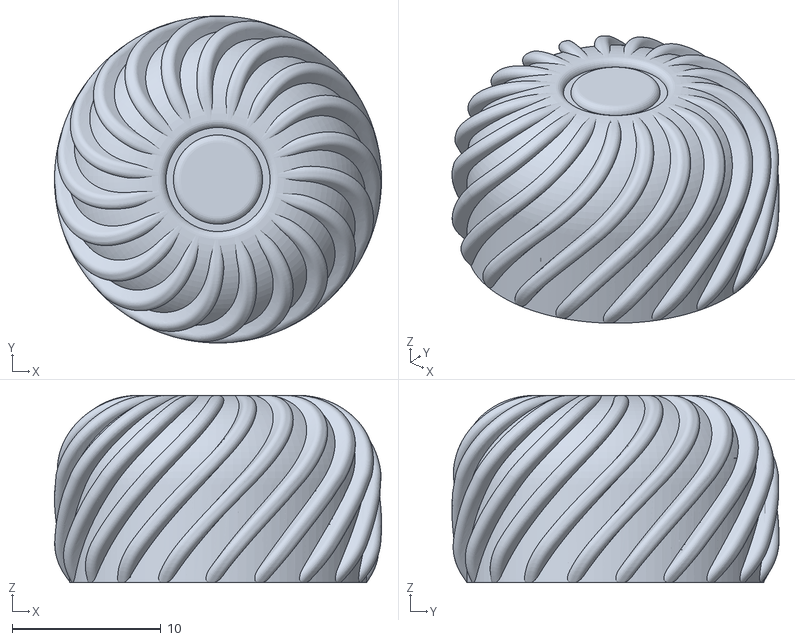
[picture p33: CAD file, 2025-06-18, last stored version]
printables/Encoder-Knobs/EC11/EC-11-Encoder-Knob-for-Drift-Keyboard-bigboi.stl
22.0 x 22.0 x 12.6

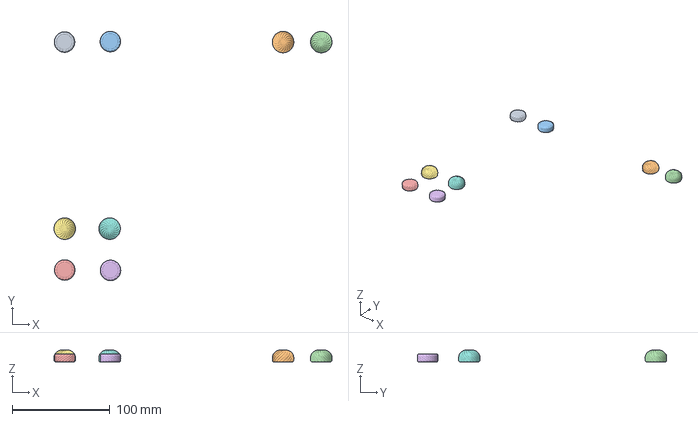
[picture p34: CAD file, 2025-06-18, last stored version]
printables/Encoder-Knobs/EC12/EC-12-Encoder-Knobs-for-Drift-Keyboard-V4.3mf
284.9 x 255.5 x 12.0 mm
EC-12 Encoder Knob 20x8 mm.stl x 4
EC-12 Encoder Knob Round BOI mm.stl x 4

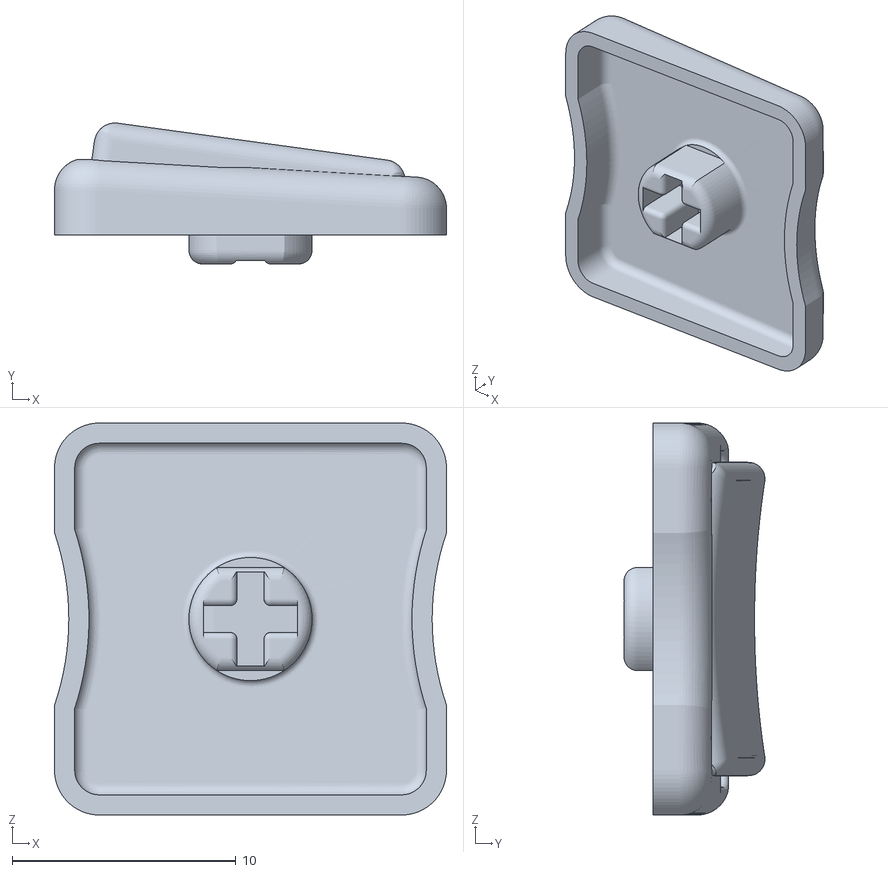
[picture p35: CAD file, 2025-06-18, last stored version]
printables/Low-Profile/Otaru-Keycaps-by-Timception-(Low-Profile)-Thumb-Key.stl
17.5 x 6.29 x 17.5

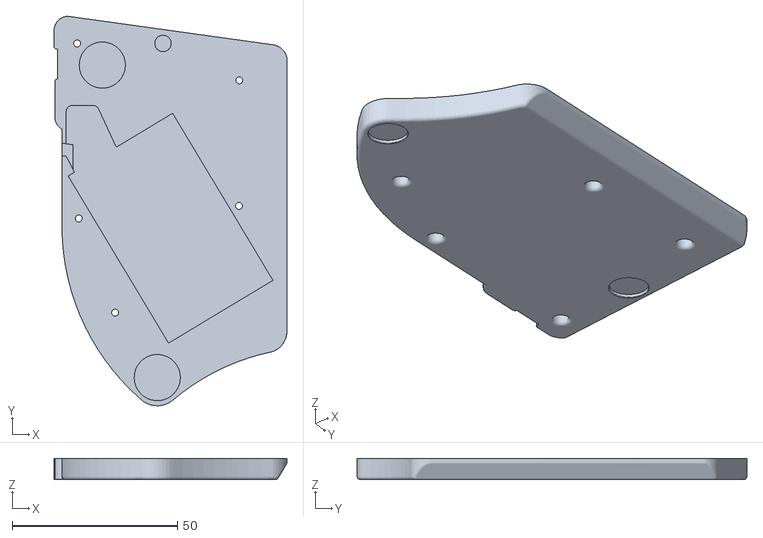
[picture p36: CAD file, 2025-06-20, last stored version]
PS3 Battery Pack Assembly/Drift-V3-Battery-Expansion/Drift-V3-Battery-Expansion-right.stl
70.5 x 118.0 x 6.50

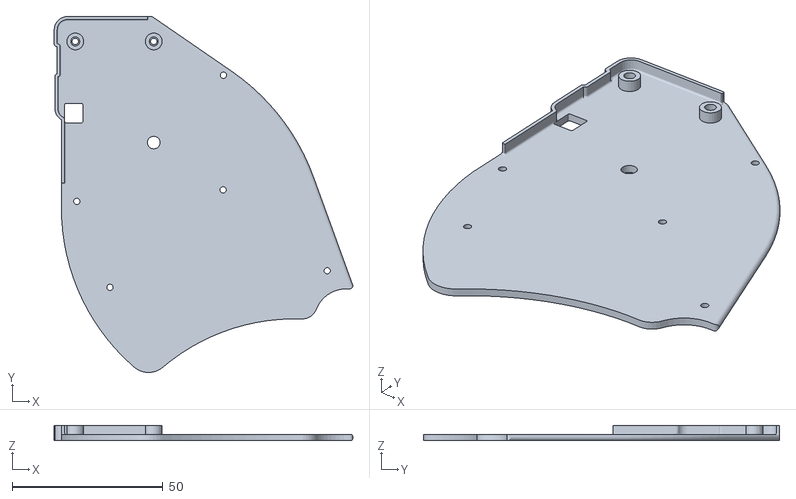
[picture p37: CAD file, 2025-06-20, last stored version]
PS3 Battery Pack Assembly/Drift-V3-Bottom-Pieces/Drift-V3-Bottom-Piece-4.stl
99.0 x 118.0 x 5.00

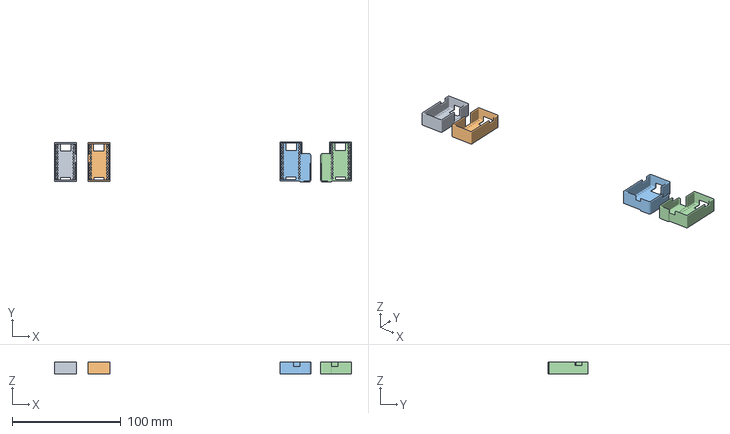
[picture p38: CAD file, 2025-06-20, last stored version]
V3-MCU-Cover/MCU-Cover.3mf
273.1 x 36.9 x 11.0 mm
MCU Cover for Pro Micro v3.stl x 2
MCU Cover for Pro Micro v8.stl x 2

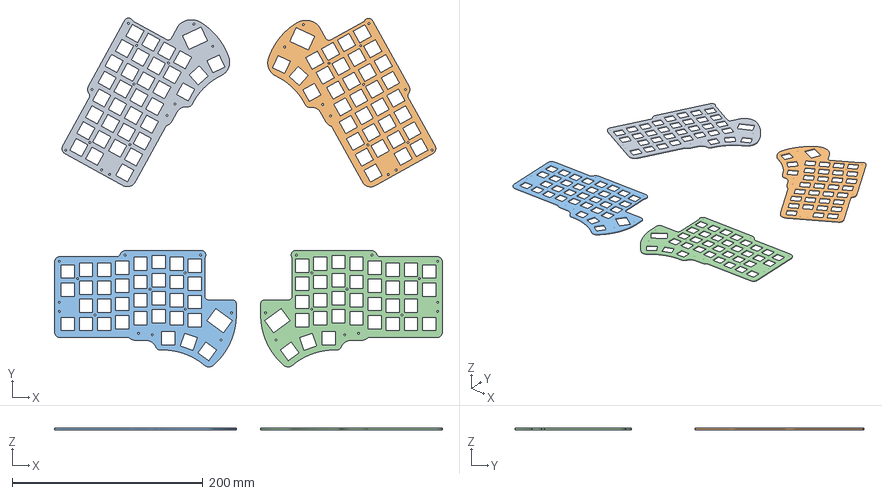
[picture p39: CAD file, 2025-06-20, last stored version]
Drift-V2-and-V3-Choc-Plates/Drift-V2-and-V3-Choc-Plates.3mf
406.6 x 365.6 x 2.00 mm
Drift V4 Choc Plate A1 Mini.stl x 2
Drift-V2-and-V3-Full-Size-Choc-Plate-left.stl
Drift-V2-and-V3-Full-Size-Choc-Plate-right.stl

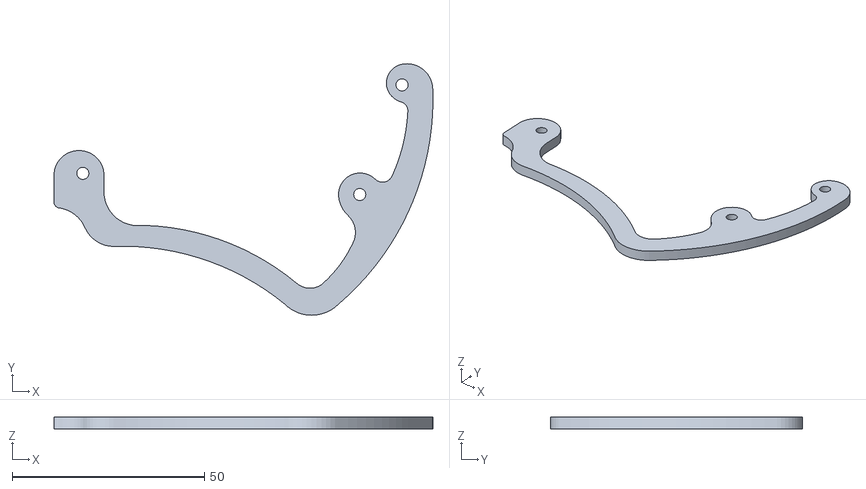
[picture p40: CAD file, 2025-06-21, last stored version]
Outer-Acrylic/Bottom-Right-Acrylic.stl
98.6 x 65.4 x 3.00

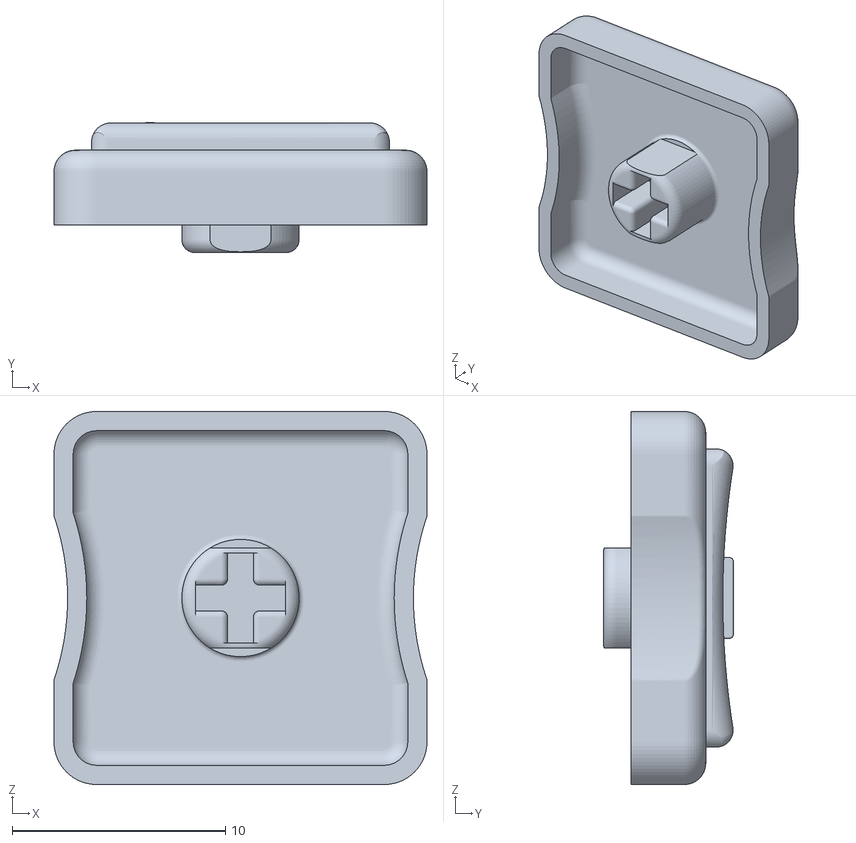
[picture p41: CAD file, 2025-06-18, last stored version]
printables/Low-Profile/Otaru-Keycaps-by-Timception-(Low-Profile)-Ribbed-Key.stl
17.5 x 6.10 x 17.5

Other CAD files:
Drift-V2-and-V3-Cherry-Plates/Drift-V2-and-V3-Full-Size-Cherry-MX-Plate-right.stl
Drift-V2-and-V3-Cherry-Plates/Drift-V2-and-V3-Full-Size-Cherry-MX-Plate-left.stl
Drift-V2-and-V3-Choc-Plates/Drift-V2-and-V3-Full-Size-Choc-Plate-left.stl
printables/Cherry-MX/Otaru-Keycaps-by-Timception-Normal-Key.stl
PS3 Battery Pack Assembly/Drift-V3-Battery-Expansion/Drift-V3-Battery-Expansion-left.stl
Outer-Acrylic/Bottom-Left-Acrylic.stl
Outer-Acrylic/Outer-Acrylic.3mf
Outer-Acrylic/Top-Acrylic.stl
PS3 Battery Pack Assembly/Drift-V3-Battery-Expansion/Drift-V3-Battery-Expansion.3mf
PS3 Battery Pack Assembly/Drift-V3-Bottom-Pieces/Drift-V3-Bottom-Piece-1.stl
PS3 Battery Pack Assembly/Drift-V3-Bottom-Pieces/Drift-V3-Bottom-Piece-2.stl
PS3 Battery Pack Assembly/Drift-V3-Bottom-Pieces/Drift-V3-Bottom-Piece-3.stl
PS3 Battery Pack Assembly/Drift-V3-Bottom-Pieces/Drift-V3-Bottom-Pieces.3mf
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
